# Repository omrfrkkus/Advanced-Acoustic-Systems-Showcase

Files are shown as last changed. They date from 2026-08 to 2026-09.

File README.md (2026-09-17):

# 🔊 Advanced Custom Acoustic Systems — Hardware Showcase

<p align="center">
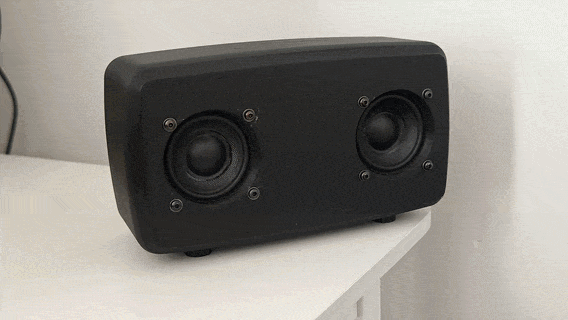
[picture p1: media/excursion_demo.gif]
High Excursion Drivers in Action
  
</p>

> **Note:** This repository contains the architectural overviews, DSP tuning strategies, and CAD files (`/stl_files`) for two distinct, fully functional 3D-printed acoustic enclosures I engineered from scratch.

## 📌 Project Overview
This showcase demonstrates a full-cycle hardware engineering process, **developed entirely solo from scratch**. Driven by a hands-on approach to problem-solving, I leveraged **AI-assisted research** to independently master the required multidisciplinary skills—from CAD modeling in Autodesk Fusion to electromechanical assembly, power management, and acoustic signal processing. 

The primary goal was to overcome complex acoustic challenges (resonance, standing waves, internal volume constraints) within small 3D-printed form factors, without relying on pre-existing kits or external engineering support.

---

## 🚀 Iteration 2: High-SPL Waterproof System (DSP & Power)
*(Featured in the demo above)*

Pushing the limits of small-enclosure acoustics (<1 Liter), this advanced system focuses on deep low-frequency extension, high current delivery, and weather resistance.

> **🖨️ Open Source Hardware:** The STL files, complete BOM, and detailed build instructions for this model are publicly available on [Printables: High-SPL Custom 3D Printed Speaker (DSP Tuned)](https://www.printables.com/model/1845016-3d-printed-speaker-dsp-tuned).

* **Driver Architecture:** Features dual front-firing 4-ohm 11W Neodymium long-stroke drivers, physically coupled with a massive 135x75mm rear **Passive Radiator** to dramatically extend bass response in a sub-1L volume.
* **High-Current Power (BMS):** Engineered a 1S2P battery pack using high-drain LG HG2 18650 cells. Integrated a dedicated Battery Management System (BMS) to safely handle the high amperage spikes during heavy bass transients.
* **Digital Signal Processing (DSP):** Powered by a 2x10W amplifier. I utilized **ACPWorkbench** to digitally tune the system, surgically cutting resonant frequencies and applying custom EQ curves to maximize high-fidelity output.
* **Modular Acoustic Dampening:** The internal volume utilizes an adjustable poly-fill dampening system secured via hook-and-loop (Velcro) strips on the inner walls. This allows for rapid physical acoustic tuning (switching between a clinical flat response or maximum punch) without permanent adhesives.

### 📸 Hardware & Architecture Gallery
<p align="center">
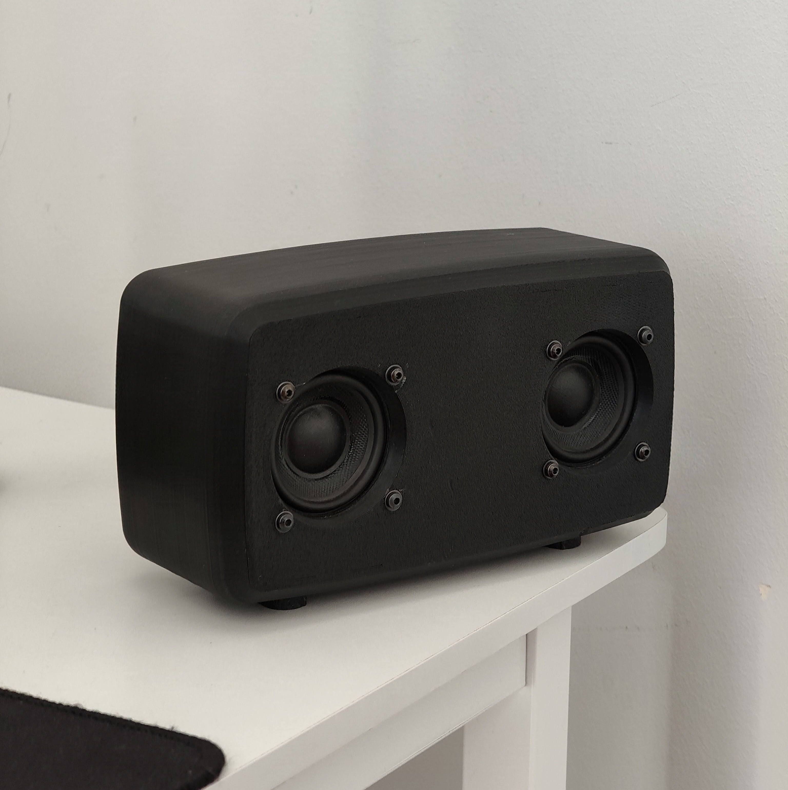
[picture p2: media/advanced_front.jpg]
High-SPL Front View
  
  &nbsp;
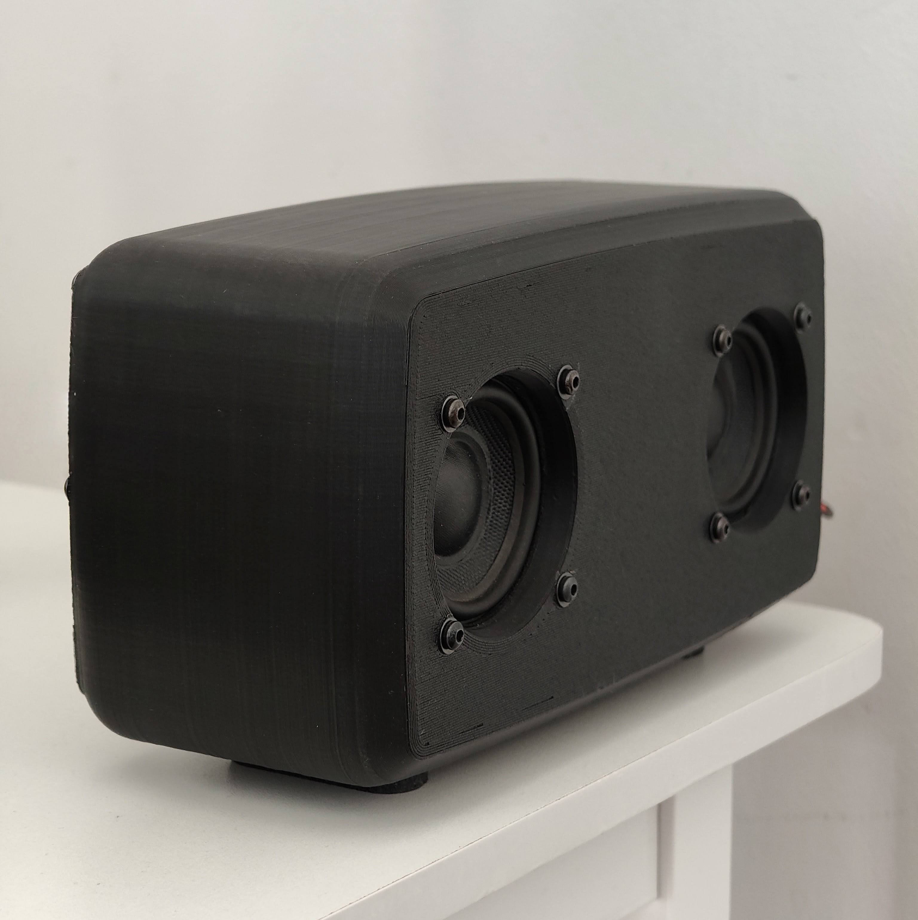
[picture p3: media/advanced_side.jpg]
High-SPL Side Profile
  
  &nbsp;
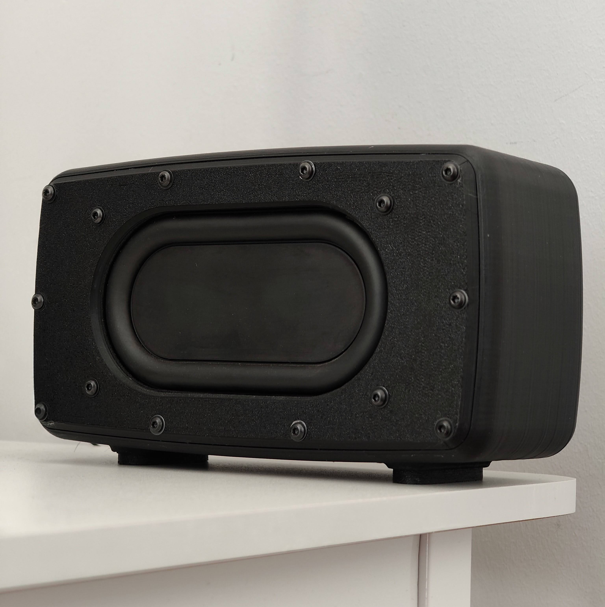
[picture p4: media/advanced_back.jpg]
High-SPL Rear Passive Radiator
  
</p>
<p align="center">
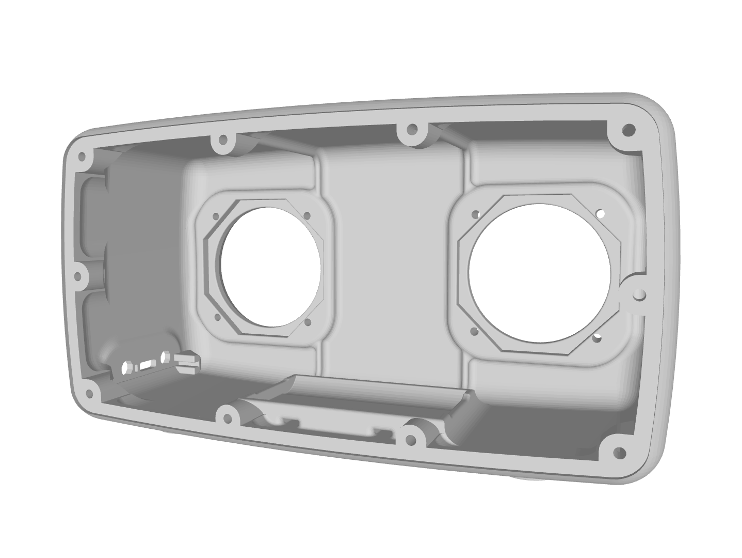
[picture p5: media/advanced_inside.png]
Internal CAD Architecture
  
  &nbsp;
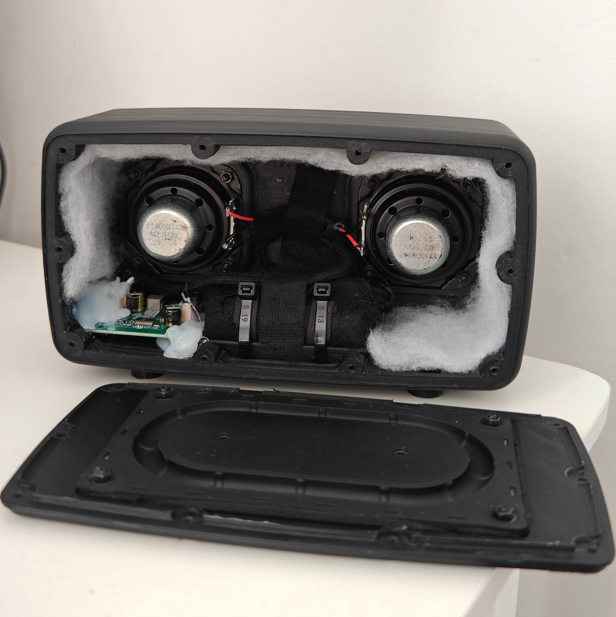
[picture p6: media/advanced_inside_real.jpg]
Real Internal Wiring & Dampening
  
</p>

### 🎥 Acoustic Performance & Stress Tests
Real-world volume, excursion, and dynamic output testing under load:

<p align="center">
  <a href="https://youtu.be/s3fn8n4pkiM" target="_blank">
    Speaker Project %80 Volume Test
  </a>
  &nbsp;
  <a href="https://youtu.be/kctdLXoFfMA" target="_blank">
    Speaker Project Max Volume Test
  </a>
</p>

| Test Video | Test Description | Duration |
| :--- | :--- | :---: |
| 🔊 [Speaker Project %80 Volume Test](https://youtu.be/s3fn8n4pkiM) | High dynamic range evaluation measuring bass response, clarity, and driver linearity. | `0:41` |
| 🔊 [Speaker Project Max Volume Test](https://youtu.be/kctdLXoFfMA) | Full-power stress test verifying BMS surge handling and structural resonance elimination. | `0:20` |

---

## 🛠️ Iteration 1: Spherical TWS System (Acoustic Geometry)
The initial prototype focused on geometric acoustic treatment, power efficiency, and wireless synchronization. Built as a paired set for True Wireless Stereo (TWS) operation.

> **🖨️ Open Source Hardware:** The STL files and complete build instructions for this model are publicly available on [Printables: Sphere TWS Speakers](https://www.printables.com/model/1825186-sphere-tws-speakers).

* **Acoustic Design (600ml):** Engineered a spherical closed-box enclosure. The internal walls feature a custom 3D-printed **pyramid diffuser matrix** to break up standing waves and minimize unwanted internal resonance.
* **Hardware Specs:** Driven by a single 4-ohm 5W full-range driver per unit, powered by a Bluetooth/TWS amplifier with Type-C and AUX inputs.
* **Power Management:** Operates efficiently on a single 18650 lithium-ion cell per unit, delivering exceptional battery life for long-duration playback.

### 📸 Hardware & Architecture Gallery
<p align="center">
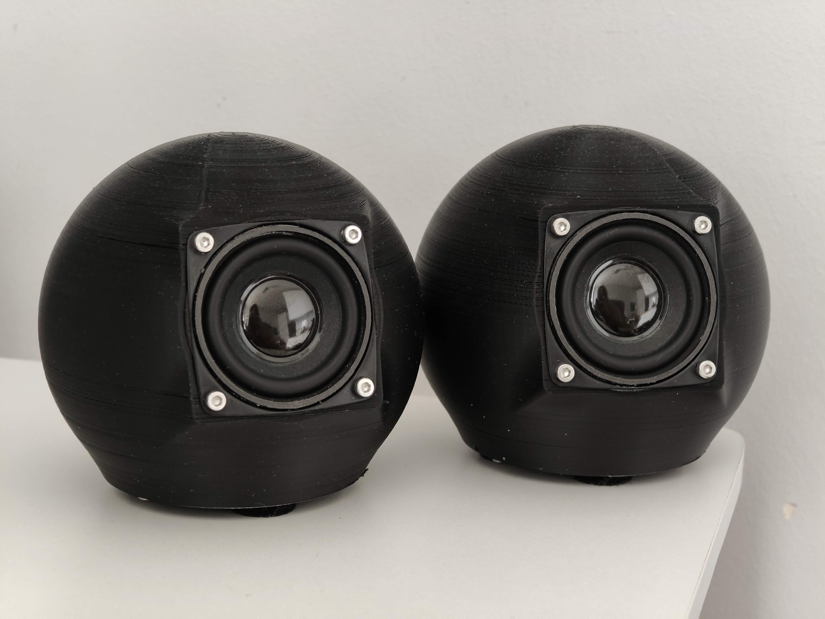
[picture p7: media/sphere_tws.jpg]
Spherical TWS Speakers
  
  &nbsp;
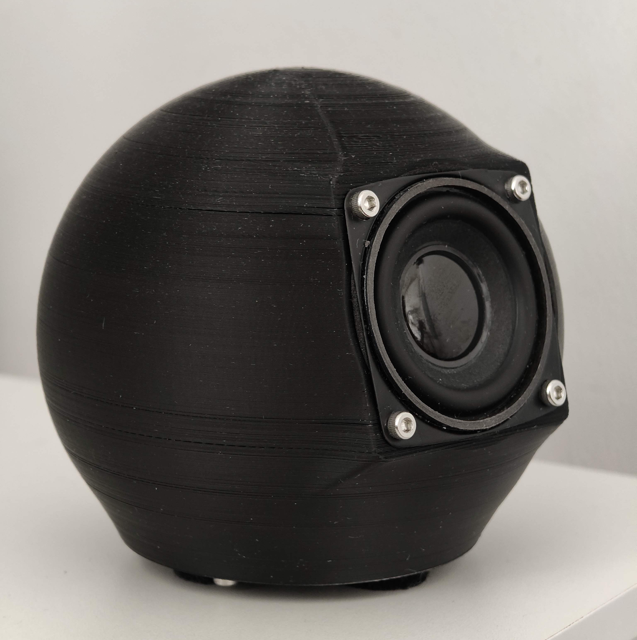
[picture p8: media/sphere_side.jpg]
Sphere Side Profile
  
</p>
<p align="center">
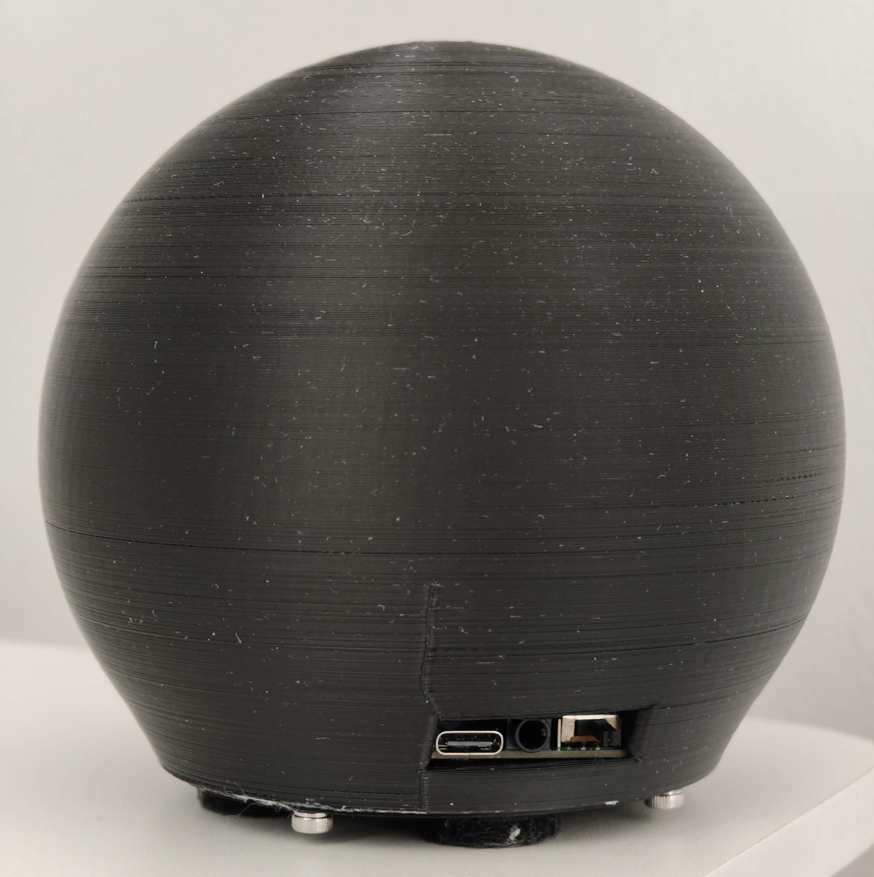
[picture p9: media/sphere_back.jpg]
Sphere Rear Ports
  
  &nbsp;
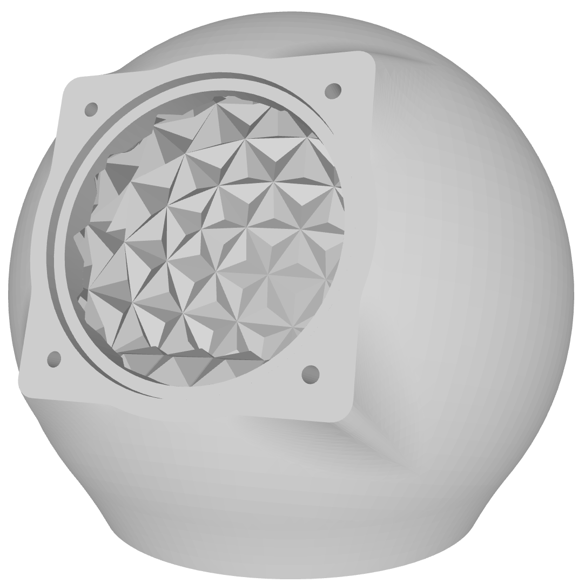
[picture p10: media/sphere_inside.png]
Internal Pyramid Matrix CAD
  
</p>

### 🎥 Spherical TWS Acoustic Tests
Acoustic performance and distortion tests in dual-speaker paired mode:

<p align="center">
  <a href="https://youtu.be/pdXcFrA3jAQ" target="_blank">
    Sphere Speaker TWS %70 Volume Test
  </a>
  &nbsp;
  <a href="https://youtu.be/vx8ZYlDZn7Q" target="_blank">
    Sphere Speaker TWS Max Volume Test
  </a>
</p>

| Test Video | Test Description | Duration |
| :--- | :--- | :---: |
| 🔊 [Sphere Speaker TWS %70 Volume Test](https://youtu.be/pdXcFrA3jAQ) | Mid-high volume clarity test with wireless stereo separation in a 600ml spherical chamber. | `0:56` |
| 🔊 [Sphere Speaker TWS Max Volume Test](https://youtu.be/vx8ZYlDZn7Q) | Maximum output test assessing enclosure rigidness and passive anti-resonance effectiveness. | `1:01` |

---

## 🔩 Structural Engineering & Manufacturing Pipeline
Both systems were manufactured with a strict focus on structural integrity, utilizing custom slicing profiles and mechanical isolation techniques.

* **Internal Bracing & Infill:** Designed custom internal ribbing structures within the CAD models. Slicer profiles were optimized using **Gyroid infill** (minimum 4-5 walls) to provide multi-directional structural strength, preventing panel resonance and acoustic energy loss.
* **Hermetic Chamber Sealing:** Acoustic performance relies on a strict closed-box system. To guarantee a 100% airtight seal for the passive radiator and drivers, the top mating layers were printed utilizing a slicer **"Ironing"** pass to create a glass-flat surface. External assemblies are secured with M3 screws, EVA foam isolation tape (gaskets), and dielectric grease. Internal wire routing holes connecting the acoustic chamber to the electronics bay were hermetically sealed with adhesive.
* **Internal Rattle Prevention:** To prevent internal wiring from vibrating against the plastic walls during high SPL output, all cables were wrapped in automotive fleece tape and secured directly to the chassis.
* **Electromechanical Safety:** Strict safety protocols were implemented for power management, including proper BMS integration and spot-welding/soldering procedures to prevent thermal runaway or short circuits in the 18650 lithium-ion cells.
* **Vibration Isolation:** Designed and printed custom **TPU (Thermoplastic Polyurethane)** feet to decouple the speakers from resting surfaces, preventing external rattle and acoustic coloration.
* **Extreme Stress Testing:** Prior to electronic assembly, the empty enclosures underwent severe dynamic load testing—successfully withstanding the full dynamic weight of an adult jumping on them without any mechanical deformation, micro-fractures, or seal failures.

---

## 📂 Repository Contents
* `/stl_files` - Contains the 3D printable CAD models for both iterations.
* `/media` - High-resolution photos, CAD screenshots, and performance GIFs.

## 📬 Contact
* **Email:** [omerfaruk.kus@outlook.com](mailto:omerfaruk.kus@outlook.com)
* **LinkedIn:** [linkedin.com/in/omrfrkkus](https://linkedin.com/in/omrfrkkus)

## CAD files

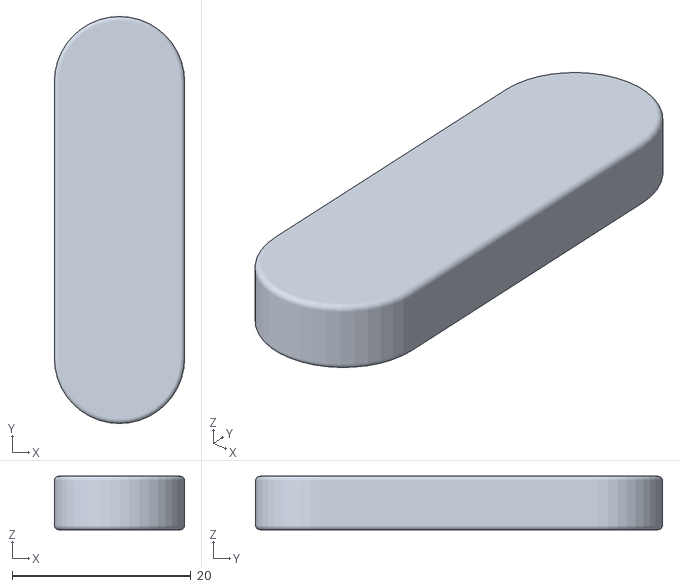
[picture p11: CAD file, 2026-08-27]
stl_files/high_spl_waterproof_tpu_feet.stl
14.6 x 45.6 x 6.00

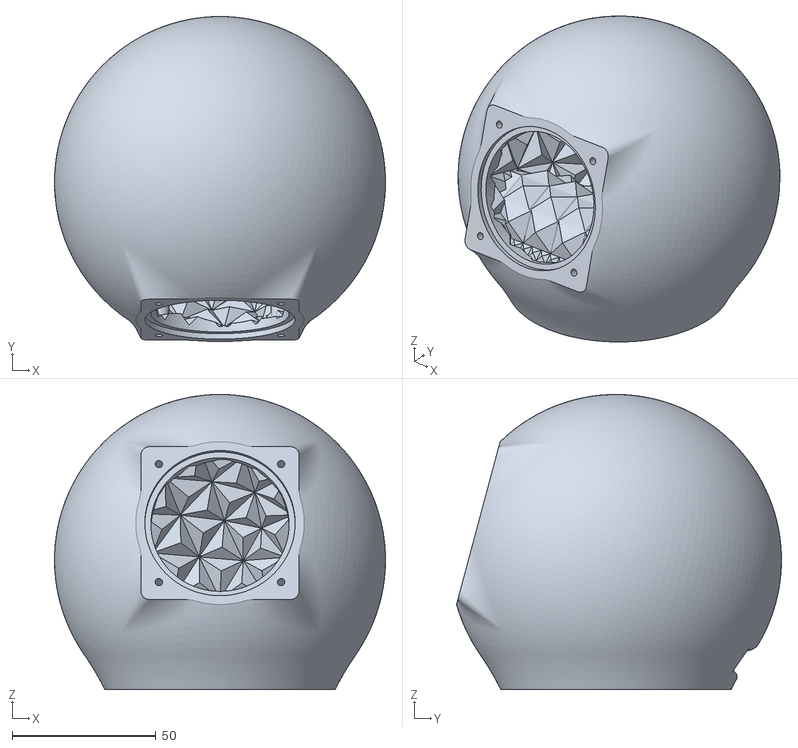
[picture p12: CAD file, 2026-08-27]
stl_files/sphere.stl
115.0 x 112.9 x 102.5

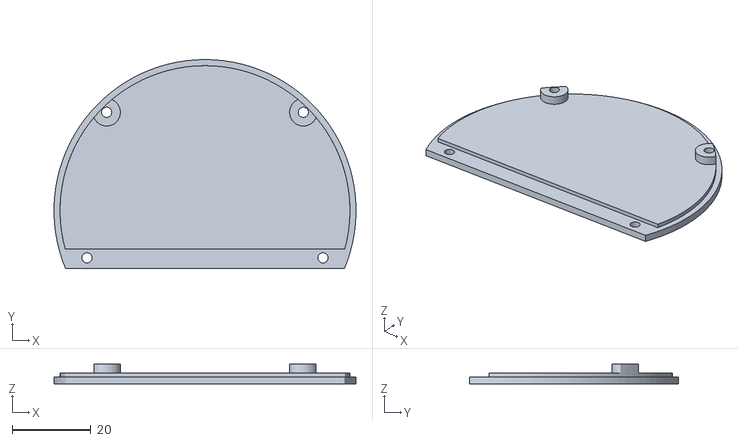
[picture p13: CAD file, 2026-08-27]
stl_files/sphere_cap.stl
76.8 x 53.1 x 5.00

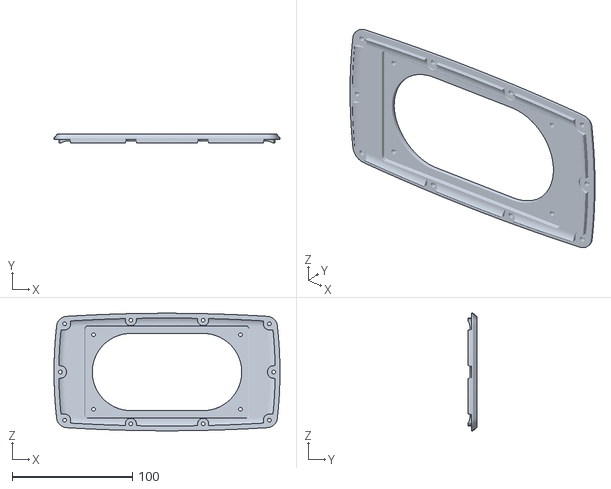
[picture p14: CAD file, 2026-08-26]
stl_files/high_spl_waterproof_cap.stl
187.6 x 7.60 x 97.6

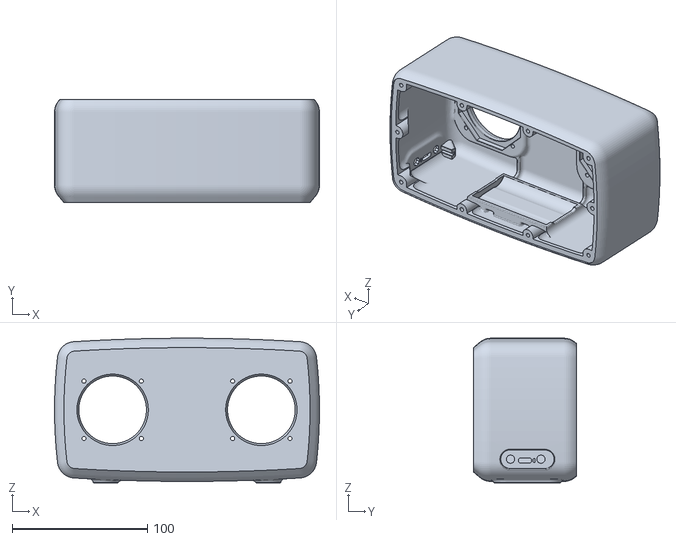
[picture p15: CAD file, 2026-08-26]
stl_files/high_spl_waterproof.stl
196.0 x 76.4 x 107.0

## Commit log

2026-08-27 Rename High-SPL Waterproof Cap.stl to high_spl_waterproof_cap.stl
    [high_spl_waterproof_cap.stl]
2026-08-27 Rename High-SPL Waterproof.stl to high_spl_waterproof.stl
    [High-SPL Waterproof.stl, high_spl_waterproof.stl]
2026-09-17 Revise speaker specifications and enhance sealing methods
    Updated driver specifications and improved acoustic dampening description. Enhanced hermetic sealing details and added internal rattle prevention measures.
